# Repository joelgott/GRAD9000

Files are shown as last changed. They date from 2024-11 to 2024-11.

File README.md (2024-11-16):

# Description

This project is strongly inspired by the HAL9000 robot from Stanley Kubrick's 2001 Space Odyssey. I used an ESP32 based board for the main logic and an audio module so that it looks like it's talking. Most of the mechanical parts are recicled or 3D printed.
This repository contains all the contents for making and programming the robot.

## Hardware

This robot uses a [seed studio XIAO ESP32-c3 development board](https://wiki.seeedstudio.com/XIAO_ESP32C3_Getting_Started/) with a [DFPlayer audio module](https://www.dfrobot.com/product-1121.html). 
In the PCB folder there is a custom designed PCB that contains both boards, recieves a 5V input and has, a servo controller connector, an i2c bus output, a rgb led pinout and a speaker output. There is also a socket for an adxl345 accelerometer and other audio output that can go to an amplifier.

## Software

In the Circuitpython folder there is the code that runs on the robot. There are two files, the one called eyetest lets me play with the rgb led to try animations and such. The other one called grad9000 contains the logic for controlling the audio module, reading the json file and switching the green led while maintaining the red one permanently on so that it looks like it's talking. 

## Extras

I also made a python script that lets you generate a json file that contains the information of the audio files. This json file can then be uploaded to the robot so it knows the duration of each audio file and how many are in each folder.

## Contributing

Pull requests are welcome. For major changes, please open an issue first
to discuss what you would like to change.

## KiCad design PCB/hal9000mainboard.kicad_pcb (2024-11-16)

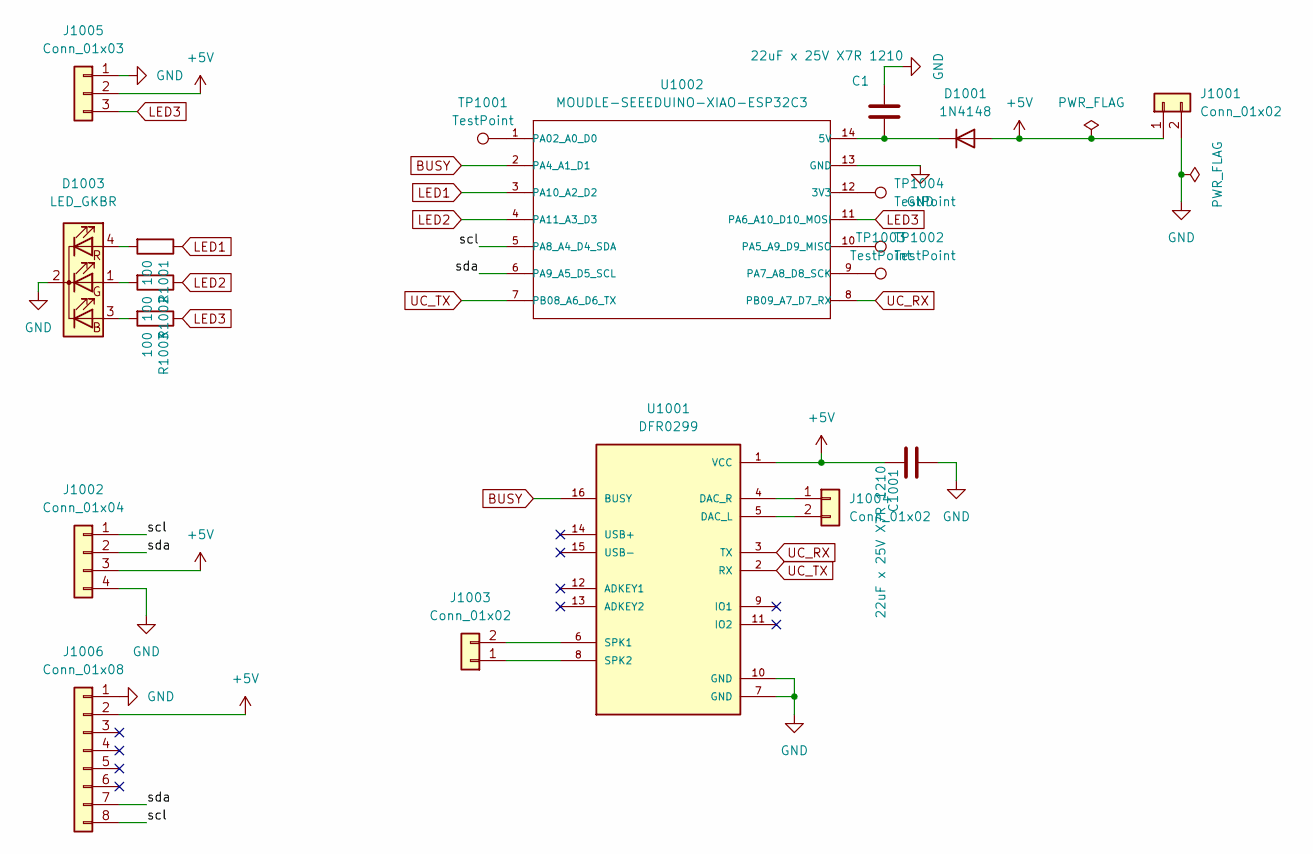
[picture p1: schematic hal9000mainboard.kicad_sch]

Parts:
C1, C1001: 22uF x 25V X7R 1210; C_Rect_L4.0mm_W2.5mm_P2.50mm; Digikey Code 1276-3392-1-ND
D1001: 1N4148; D_DO-35_SOD27_P7.62mm_Horizontal
D1003: LED_GKBR; LED_D5.0mm-4_RGB_Wide_Pins
J1001: Conn_01x02; PhoenixContact_MCV_1,5_2-G-3.81_1x02_P3.81mm_Vertical
J1002: Conn_01x04; PinHeader_1x04_P2.54mm_Vertical
J1003, J1004: Conn_01x02; TerminalBlock_bornier-2_P5.08mm
J1005: Conn_01x03; PinHeader_1x03_P2.54mm_Vertical
J1006: Conn_01x08; PinHeader_1x08_P2.54mm_Vertical
R1001, R1002, R1003: 100; R_0603_1608Metric; Digikey Code 2019-RK73H1JRTTD2200FCT-ND
TP1001, TP1002, TP1003, TP1004: TestPoint; TestPoint_Pad_3.0x3.0mm
U1001: DFR0299; MODULE_DFR0299
U1002: MOUDLE-SEEEDUINO-XIAO-ESP32C3; XIAO-Generic-Hybrid-14P-2.54-21X17.8MM

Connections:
+5V: C1001.1, D1001.2 (A), J1001.1, J1002.3, J1005.2, J1006.2, U1001.1 (VCC)
/scl: J1002.1, J1006.8, U1002.5 (PA8_A4_D4_SDA)
/sda: J1002.2, J1006.7, U1002.6 (PA9_A5_D5_SCL)
BUSY: U1001.16 (BUSY), U1002.2 (PA4_A1_D1)
GND: C1.2, C1001.2, D1003.2 (K), J1001.2, J1002.4, J1005.1, J1006.1, U1001.7 (GND), U1001.10 (GND), U1002.13 (GND)
LED1: R1001.1, U1002.3 (PA10_A2_D2)
LED2: R1002.1, U1002.4 (PA11_A3_D3)
LED3: J1005.3, R1003.1, U1002.11 (PA6_A10_D10_MOSI)
unnamed: C1.1, D1001.1 (K), U1002.14 (5V)
unnamed: D1003.3 (BA), R1003.2
unnamed: D1003.1 (GA), R1002.2
unnamed: D1003.4 (RA), R1001.2
unnamed: J1003.1, U1001.8 (SPK2)
unnamed: J1003.2, U1001.6 (SPK1)
unnamed: J1004.1, U1001.4 (DAC_R)
unnamed: J1004.2, U1001.5 (DAC_L)
unnamed: TP1004.1, U1002.12 (3V3)
unnamed: TP1001.1, U1002.1 (PA02_A0_D0)
unnamed: TP1002.1, U1002.10 (PA5_A9_D9_MISO)
unnamed: TP1003.1, U1002.9 (PA7_A8_D8_SCK)
UC_RX: U1001.3 (TX), U1002.8 (PB09_A7_D7_RX)
UC_TX: U1001.2 (RX), U1002.7 (PB08_A6_D6_TX)

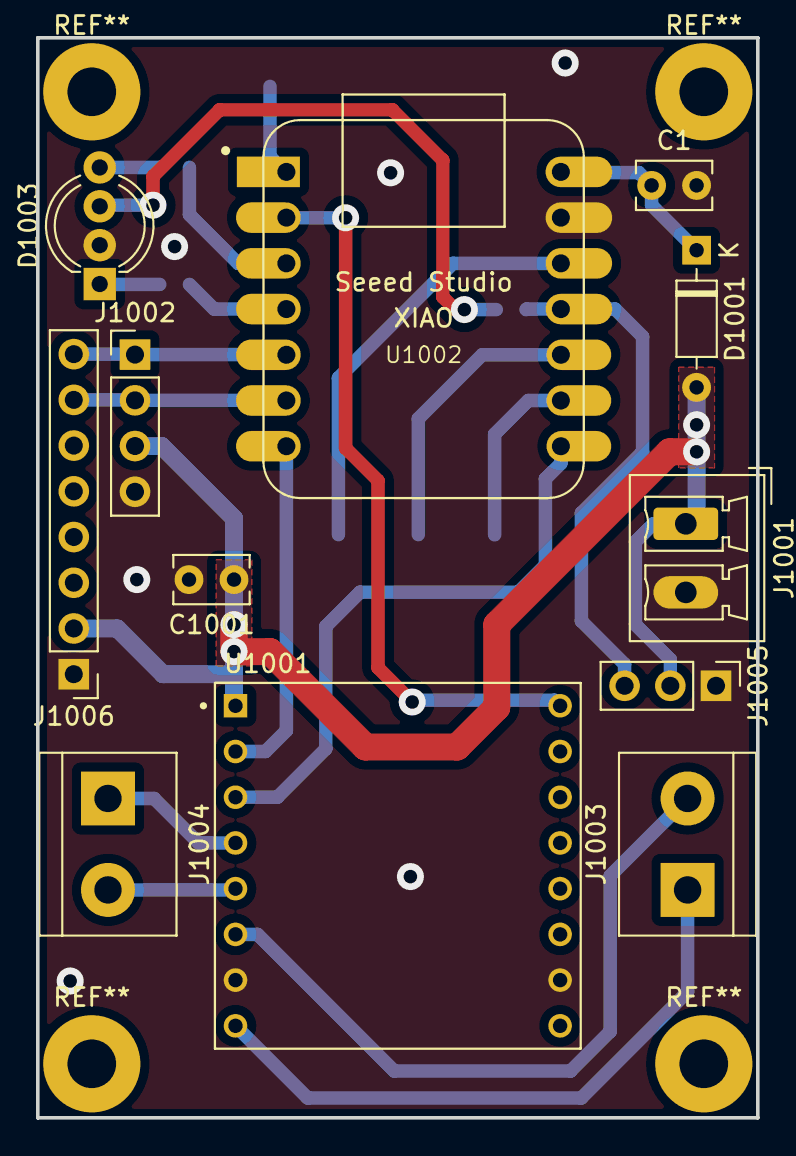
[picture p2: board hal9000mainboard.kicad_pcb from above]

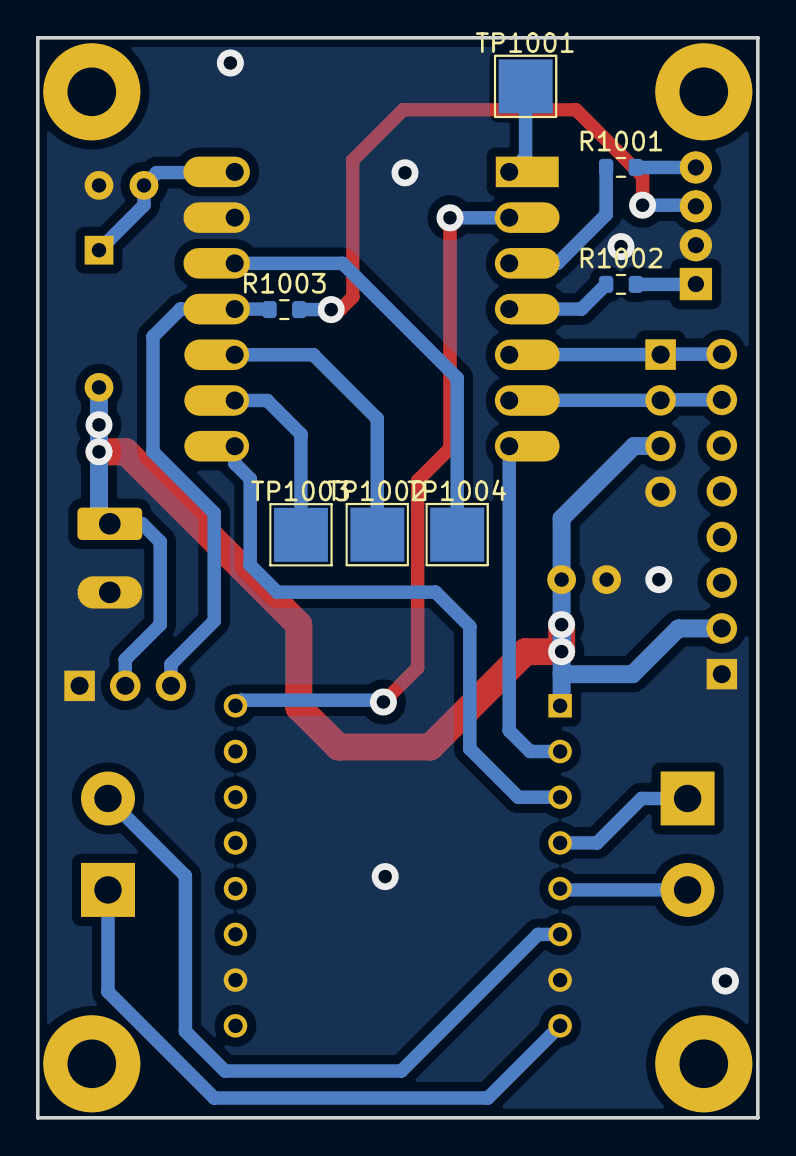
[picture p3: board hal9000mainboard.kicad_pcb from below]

Board: 2 copper layers, 40.0 x 60.0 mm, 19 parts (7 on the bottom side), 22 nets.

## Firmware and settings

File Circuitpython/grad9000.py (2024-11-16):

import board
import digitalio
from DFPlayer import DFPlayer
import asyncio
import busio
import pwmio
import json
import random
import time

class grad9000():
    def __init__(self):
        self.busy = digitalio.DigitalInOut(board.D1)
        self.uart = busio.UART(tx=board.D6, rx=board.D7, baudrate=9600)
        self.dfp = DFPlayer(self.uart, volume=70)
        self.redled = pwmio.PWMOut(board.D3, frequency=25000, duty_cycle=0)
        self.greenled = pwmio.PWMOut(board.D2, frequency=25000, duty_cycle=0)
        with open('audios.json') as json_file:
            self.audios = json.load(json_file)
            
    async def start(self, wait_time):
        max = 100
        max_2 = max*max
        for i in range(max):
            self.redled.duty_cycle = int(32000*(i*i/max_2))
            await asyncio.sleep_ms(int(wait_time/max))    

    async def blink(self, led, wait_time, duty = 65535):
        led.duty_cycle = duty
        await asyncio.sleep_ms(int(wait_time/2))   
        led.duty_cycle = 0
        await asyncio.sleep_ms(int(wait_time/2))

    async def perma_blink(self, led, wait_time, duty):
        while True:
            await self.blink(led, wait_time, duty)

    async def random_blink(self, led, wait_time, segments = 5):
        for i in range(segments):
            duty = random.randint(10000,40000)
            led.duty_cycle = duty
            await asyncio.sleep_ms(int(wait_time/segments))

    def get_folder_name_from_id(self, id):
        return next((item for item in self.audios if self.audios[item].get('id') == id))
    
    def get_song_dict_from_id(self, folder, id):
        return next((item for item in self.audios[folder]['canciones'] if item.get('id') == id))
    
    def play(self, folder, song):
        if isinstance(folder, int) and isinstance(song, int):
            self.dfp.play(folder,song)
            folder_name = self.get_folder_name_from_id(folder)
            song_item = self.get_song_dict_from_id(folder_name, song)
            return song_item['duracion']
        if isinstance(folder, str) and isinstance(song, str):
            song_item = next((item for item in self.audios[folder]['canciones'] if item["nombre"] == song), None)
            self.dfp.play(self.audios[folder]['id'], song_item['id'])
            return song_item['duracion']
        
    def play_random(self, folder):
        folder_name = self.get_folder_name_from_id(folder)
        dur = self.play(folder, random.randint(1,len(self.audios[folder_name]['canciones'])-1))
        return dur

    def pause(self):
        self.dfp.pause()
        
async def main():
    hal = grad9000()
    await hal.start(1000)
    dur = hal.play_random(1)
    print(dur)
    await hal.random_blink(hal.greenled, int(dur*1000), 10)
if __name__ == "__main__":
    asyncio.run(main())

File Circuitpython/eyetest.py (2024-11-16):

import pwmio
import asyncio
import board
import random

async def blink(led, wait_time, duty = 65535):
    led.duty_cycle = duty
    await asyncio.sleep_ms(int(wait_time/2))   
    led.duty_cycle = 0
    await asyncio.sleep_ms(int(wait_time/2))

async def perma_blink(led, wait_time, duty):
    while True:
        await blink(led, wait_time, duty)

async def random_blink(led, wait_time, segments = 5):
    for i in range(segments):
        duty = random.randint(10000,40000)
        led.duty_cycle = duty
        await asyncio.sleep_ms(int(wait_time/segments))

async def start(led, wait_time):
    maxcicles = 100
    max_2 = maxcicles*maxcicles
    for i in range(maxcicles):
        led.duty_cycle = int(32000*(i*i/max_2))
        await asyncio.sleep_ms(int(wait_time/maxcicles))

async def main():
    redled = pwmio.PWMOut(board.D3, frequency=25000, duty_cycle=0, variable_frequency=True)
    greenled = pwmio.PWMOut(board.D2, frequency=25000, duty_cycle=0, variable_frequency=True)  
    #await blink(greenled,500)
    await start(redled,1000)
    
    #asyncio.create_task(perma_blink(greenled,200, 20000))
    #await asyncio.sleep_ms(5000) 
    await random_blink(greenled, 2000, 20)

if __name__ == "__main__":
    asyncio.run(main())
